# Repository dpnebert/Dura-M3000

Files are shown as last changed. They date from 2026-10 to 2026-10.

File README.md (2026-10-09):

# Dura M-3000

Firmware and hardware design files for the **Dura M-3000 liquid metering and pump-control system**.

The M-3000 uses an ESP32-S3 controller with a local LCD/keypad interface and Bluetooth Low Energy (BLE) communication for the Dura app. This project uses the single-meter M3000 configuration; the networked Dura V2 / ESP-NOW configuration is a separate product scope.

## Repository layout

```text
.
├── README.md
├── firmware/                 # ESP-IDF application, configuration and tests
│   ├── main/                 # Application startup and command handling
│   ├── components/           # Board support, metering, control and BLE modules
│   ├── scripts/              # Regression checks and development/bench utilities
│   ├── tests/                # Host-side test fixtures and supporting code
│   ├── tools/                # Asset conversion utilities
│   ├── CMakeLists.txt        # ESP-IDF project definition
│   ├── sdkconfig             # Saved project configuration
│   ├── sdkconfig.defaults    # Baseline configuration defaults
│   ├── dependencies.lock     # Resolved component and ESP-IDF versions
│   └── version.txt           # Build version identifier
└── hardware/                 # Schematic and PCB design files
```

## Functionality

- Flow measurement and volume display in gallons, liters and ounces.
- Manual dispensing, automatic batching and recirculation controls.
- Pump, injection-valve and recirculation-valve output control.
- Calibration workflows and persistent meter settings.
- Local LCD/keypad operation and BLE command handling.
- Battery monitoring, backlight control and deep-sleep support.

## Hardware platform

The firmware baseline targets the **PCB832 revX3 controller**, with the **PCB790 pump/relay interface** forming part of the system hardware.

| Item | Firmware baseline / intended system |
| --- | --- |
| Module | Espressif `ESP32-S3-WROOM-1-N8R2` |
| ESP-IDF target | `esp32s3` |
| Flash | 8 MB |
| PSRAM | Disabled in the firmware configuration |
| Display | 128 × 64 LCD with keypad input |
| Communications | BLE; UART0 for programming and console access |
| System power | Nominal 12 V lead-acid battery |
| CAD workflow | DipTrace |

Use the exact schematic, PCB revision and fitted parts for the unit being assembled. The nominal battery voltage is not a specification for the complete operating or transient voltage range. Hardware changes may require corresponding GPIO, polarity or configuration changes in the firmware.

## Build the firmware

### Prerequisites

- **ESP-IDF v6.0.2**, matching the checked-in dependency lockfile and verified project build baseline.
- The ESP32-S3 toolchain and Python environment installed through ESP-IDF.
- An activated ESP-IDF terminal. On Windows, use the ESP-IDF terminal or the ESP-IDF VS Code extension's terminal.

See Espressif's [ESP32-S3 setup guide](https://docs.espressif.com/projects/esp-idf/en/stable/esp32s3/get-started/) for environment installation. Use the project version above rather than assuming the latest SDK is interchangeable.

From the repository root:

```sh
cd firmware
idf.py --version
idf.py build
```

Build output is generated under `firmware/build/`, including the application image, bootloader, partition table and debug ELF. The application image is named `dura_m3000_firmware.bin`.

The saved configuration already selects `esp32s3`, 8 MB flash and disabled PSRAM. Preserve these settings unless intentionally changing the supported hardware.

To inspect or change project configuration from `firmware/`:

```sh
idf.py menuconfig
```

Board settings are under **Dura M3000 board**. Review configuration changes against the corresponding hardware revision before building a device image.

## Program and monitor a unit

**The normal configuration enables pump and valve outputs. Make connected loads safe before flashing, resetting or running commands.** Close other applications using the serial port before programming.

From `firmware/`, replace `PORT` with the connected programmer's serial port:

```sh
idf.py -p PORT flash monitor
```

The console is configured for UART0 at 115200 baud. Exit the monitor with `Ctrl+]`.

Use the board's programming interface and its schematic for wiring. Do not apply battery voltage to ESP32 GPIO or serial signals.

When programming prebuilt binaries instead of building locally, use the bootloader, partition table, application image and flash offsets from one matched release. The ELF is for debugging, not flashing. Do not perform a full-chip erase as a routine update; it removes persistent settings and calibration data.

## Tests and development tools

Host-side regression checks are in `firmware/scripts/`, with fixtures in `firmware/tests/`. They cover areas such as configuration/GPIO mapping, meter behavior, output ownership, BLE handling, UI contracts and battery processing.

For example, from `firmware/`, run the battery-history host regression with Python 3 and a compatible host C toolchain:

```sh
python scripts/test_battery_rolling_history.py
```

Some host checks use GNU compiler/linker features; a Linux development environment or WSL is appropriate for those checks. Read a script before running it: this directory also contains utilities that communicate with hardware, not only offline tests.

Passing a host regression or compiling successfully does not establish correct physical wiring, output polarity, electrical protection or complete app/device compatibility. Verify those on the matching hardware.

## Hardware design files

The [hardware directory](hardware/) contains the design files. Maintain schematic and PCB revisions together, and associate manufacturing outputs with the revision that generated them. Component substitutions must account for electrical ratings and the actual land pattern, not just package names.

The [firmware directory](firmware/) contains the application source and its build configuration. Keep firmware changes traceable to the hardware revision they support.

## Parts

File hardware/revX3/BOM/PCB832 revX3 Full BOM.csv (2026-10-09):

# | Quantity | Name | DIST P/N | Part No | Value | RefDes | Location
1 | 3 | CAP104-25V-0603 | CAP104-25V-0603 |  | 0.1uF | C1, C2, C9 | CT3/4-28 F
2 | 4 | CAP226-10V-0805 |  | GRM21BR61A226ME51L | 22uF | C3, C7, C8, C20 | NEW PART
3 | 1 | CAP106-16V-0805 | CAP106-16V-0805 |  | 10uF | C4 | CT3/3-13 B
4 | 7 | CAP105-25V-0603 | C0603C105Z3VACTU |  | 1uF | C5, C12, C13, C15, C16, C18, C19 | CT6/3-25B
5 | 1 | CAP100-50V-0603 | CAP100-50V-0603 |  | 10pF | C6 | CT3/4-25 B
6 | 2 | CAP105-16V-0603 | CAP105-16V-0603 |  | 1uF | C10, C11 | CT3/4-31 F
7 | 1 | CAP106-50V-1206 | CAP106-50V-1206 |  | 10uF | C14 | CT3/5-51 F
8 | 1 | CAP103-50V-0603 | C0603C103J5RAC7867 |  | 10nF | C17 | CT6/5-20 B
9 | 1 | GMC31X5R227M6R3NT |  |  | CAP227-6.3V-1206 | C21 | New Part
10 | 1 | MMSZ5231B-7-F | MMSZ5231B-7-F |  | 5.1V 500mW | D1
11 | 4 | BAT54S | BAT54S |  |  | D2, D3, D5, D7
12 | 1 | B02B-XASK-1-A(LF)(SN) |  |  |  | J1
13 | 1 | 3221-10-0300-00-TR |  |  | 3221-10-0300-00-TR | J4
14 | 1 | IND470nH_20pct |  |  | 0.47uH | L1 | NEW PART
15 | 1 | AIP0630GX-2R2MPBDG |  |  | 2.2uH | L2
16 | 4 | DMG3415U-7 | DMG3415U-7 |  | FET Pch | Q1, Q2, Q3, Q4 | CT3/5-13B
17 | 5 | 2N7002 | 2N7002 |  | FET Nch | Q5, Q6, Q7, Q8, Q9 | CT6/3-24 F
18 | 2 | 10.0KXT-0603 | 10.0KXT-0603 |  | 10.0K | R1, R32 | CT6/6-22 B
19 | 3 | 316KXE-0805 | CR0805-FX-3163ELF |  | 316K | R2, R9, R19 | NEW PART
20 | 13 | 100KT-0603 | 100KT-0603 |  | 100K | R3, R5, R6, R10, R11, R13, R15, R16, R20, R24, R25, R26, R29 | CT6/6-24 B
21 | 8 | 1.0KXT-0603 | 1.0KXT-0603 |  | 1.0K | R4, R12, R21, R22, R27, R28, R30, R31 | CT6/6-04 B
22 | 4 | 1.0MEX-0603 | RHM1.00MCTR-ND |  | 1M | R7, R8, R17, R18
23 | 1 | 22E-0805 | 22E-0805 |  | 22ohm | R14
24 | 1 | 95.3KXT-0603 |  |  | 95.3K | R23 | NEW PART
25 | 2 | MK15-B-2 |  |  |  | SW1, SW2
26 | 4 | DTSHW-677T-V | DTSHW-677T-V |  | SPST-NO | SW3, SW4, SW5, SW6 | UNKNOWN
27 | 1 | ESP32-S3-WROOM-1-N4R2 w/ longer pads |  |  | ESP32-S3-WROOM-1-N4R2 | U1
28 | 1 | PE12864WRF-042H36Q |  |  |  | U2
29 | 1 | TPS61021ADSGR |  |  |  | U3
30 | 1 | TPS62902RPJR |  |  | TPS62902RPJR | U4
31 | 1 | LM66100DCKR |  |  |  | U5
32 | 3 | SMAZ5V1-13-F | SMAZ5V1-13-F |  | 5.1V | Z1, Z2, Z3 | CT1/2-08

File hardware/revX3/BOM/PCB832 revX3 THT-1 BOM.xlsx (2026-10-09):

PCB832 revX3 THT-1 BOM
# | Quantity | Name | DIST P/N | RefDes | Location
1 | 1 | B02B-XASK-1-A(LF)(SN) |  | J1 | UNKNOWN
2 | 4 | DTSHW-677T-V | DTSHW-677T-V | SW3, SW4, SW5, SW6 | UNKNOWN
3 | 1 | PE12864WRF-042H36Q | PE12864WRF-042H36Q | J1 | UNKNOWN

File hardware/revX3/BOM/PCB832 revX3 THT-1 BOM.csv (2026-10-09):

# | Quantity | Name | DIST P/N | Part No | Value | RefDes | Location
1 | 1 | B02B-XASK-1-A(LF)(SN) |  |  |  | J1
2 | 4 | DTSHW-677T-V | DTSHW-677T-V |  | SPST-NO | SW3, SW4, SW5, SW6 | UNKNOWN

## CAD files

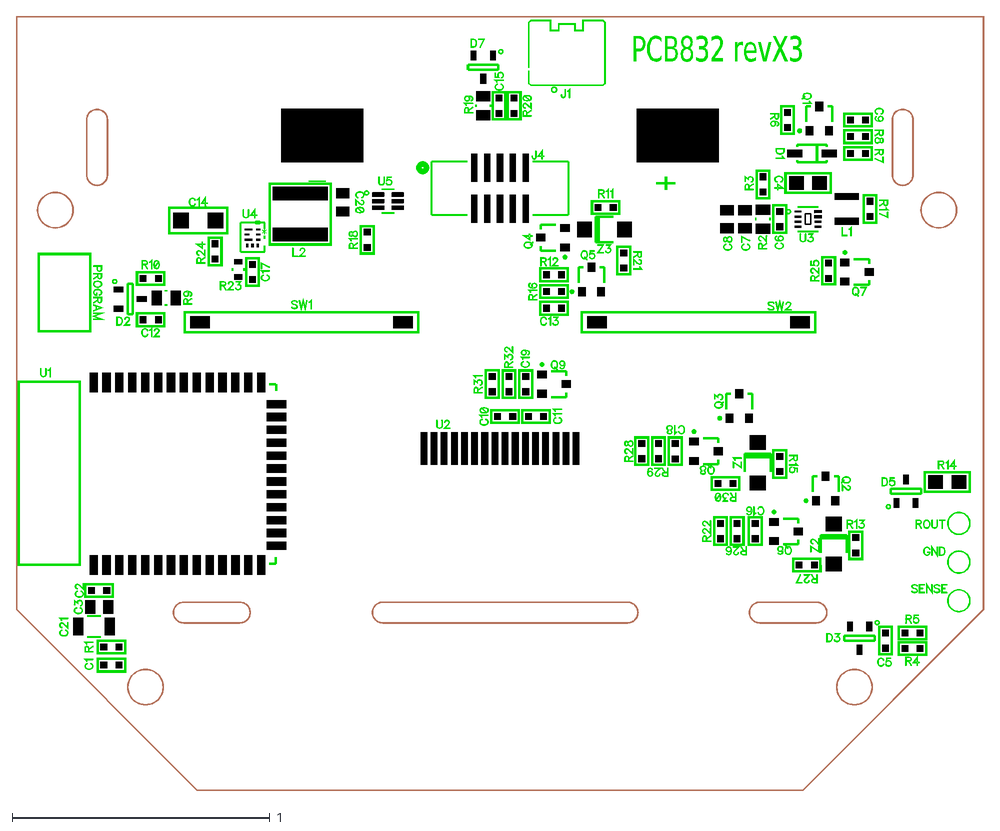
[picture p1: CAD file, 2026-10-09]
hardware/revX3/DRAWING/PCB832 revX3 SMT Ref.dxf
*
+
|
PCB832 revX3

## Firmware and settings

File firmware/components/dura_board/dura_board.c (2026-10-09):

#include "dura_board.h"
#include "gama_blefob.h"
#include "dura_battery.h"
#include "dura_st7567.h"
#include "dura_meter.h"
#include "dura_coordinator.h"
#include "dura_peers.h"
#include "dura_recipe.h"
#include "dura_lcd_assets.h"
#include "dura_ui_behavior.h"
#include "dura_ui_config.h"

#include <math.h>
#include <stdbool.h>
#include <stdio.h>
#include <string.h>
#include <strings.h>
#include "button_gpio.h"
#include "iot_button.h"
#include "driver/gpio.h"
#include "driver/rtc_io.h"
#include "esp_attr.h"
#include "esp_check.h"
#include "esp_log.h"
#include "esp_sleep.h"
#include "esp_timer.h"
#include "freertos/FreeRTOS.h"
#include "freertos/queue.h"
#include "freertos/task.h"
#include "qrcode.h"

static const char *TAG = "dura_board";
#define DURA_BOOT_LOGO_HOLD_MS 500u
#define DURA_BOOT_POWERING_UP_HOLD_MS 2000u
#define DURA_AUTO_BATCH_DEFAULT_GAL 10.0f
#define DURA_RECIRC_BATCH_DEFAULT_GAL 250.0f

static volatile uint32_t s_flow_pulses;
static portMUX_TYPE s_flow_mux = portMUX_INITIALIZER_UNLOCKED;
/* DRAM spinlock shared with the IRAM ISR; never acquire the meter from ISR. */
static portMUX_TYPE s_flow_boundary_mux = portMUX_INITIALIZER_UNLOCKED;
static QueueHandle_t s_flow_event_queue;
static portMUX_TYPE s_ui_snapshot_mux = portMUX_INITIALIZER_UNLOCKED;
static TaskHandle_t s_task;
static QueueHandle_t s_button_queue;
static dura_board_ui_snapshot_t s_ui_snapshot;
static bool s_ui_snapshot_valid;
static dura_board_ui_change_cb_t s_ui_change_cb;
static void *s_ui_change_context;
static bool s_ble_connected;
static int64_t s_last_activity_us;
/* Illumination is independent of sleep admission/connection bookkeeping. */
static int64_t s_backlight_activity_us;
static uint64_t s_activity_generation;
/* Only board_task touches preparation/recovery state and input muxes. */
static bool s_sleep_requested;
static bool s_sleep_recovery_pending;
static uint64_t s_sleep_touched_mask;
static bool s_sleep_ext1_attempted;
static bool s_ignore_buttons_until_release;
static void publish_ui_snapshot(const dura_meter_snapshot_t *meter);

esp_err_t dura_board_get_ui_snapshot(dura_board_ui_snapshot_t *snapshot)
{
    if (snapshot == NULL) return ESP_ERR_INVALID_ARG;
    portENTER_CRITICAL(&s_ui_snapshot_mux);
    if (!s_ui_snapshot_valid) {
        portEXIT_CRITICAL(&s_ui_snapshot_mux);
        return ESP_ERR_INVALID_STATE;
    }
    *snapshot = s_ui_snapshot;
    portEXIT_CRITICAL(&s_ui_snapshot_mux);
    return ESP_OK;
}

esp_err_t dura_board_set_ui_change_callback(dura_board_ui_change_cb_t callback, void *context)
{
    portENTER_CRITICAL(&s_ui_snapshot_mux);
    s_ui_change_cb = callback;
    s_ui_change_context = context;
    portEXIT_CRITICAL(&s_ui_snapshot_mux);
    return ESP_OK;
}

esp_err_t dura_board_set_ble_connected(bool connected)
{
    portENTER_CRITICAL(&s_ui_snapshot_mux);
    s_ble_connected = connected;
    ++s_activity_generation;
    s_last_activity_us = esp_timer_get_time();
    portEXIT_CRITICAL(&s_ui_snapshot_mux);
    return ESP_OK;
}

void dura_board_note_activity(void)
{
    const int64_t now_us = esp_timer_get_time();
    portENTER_CRITICAL(&s_ui_snapshot_mux);
    s_last_activity_us = now_us;
    ++s_activity_generation;
    portEXIT_CRITICAL(&s_ui_snapshot_mux);
}
void dura_board_note_user_activity(void)
{
    const int64_t now_us = esp_timer_get_time();
    portENTER_CRITICAL(&s_ui_snapshot_mux);
    s_last_activity_us = now_us;
    s_backlight_activity_us = now_us;
    ++s_activity_generation;
    portEXIT_CRITICAL(&s_ui_snapshot_mux);
}

/* Board owner only: callers on other tasks record activity, never drive GPIO.
 * No calibration exception. OFF (9) wins over every activity source. */
static void update_backlight(void)
{
    dura_meter_snapshot_t meter;
    if (dura_meter_get_snapshot(&meter) != ESP_OK) {
        (void)dura_lcd_set_backlight(false);
        return;
    }
    portENTER_CRITICAL(&s_ui_snapshot_mux);
    const int64_t activity_us = s_backlight_activity_us;
    portEXIT_CRITICAL(&s_ui_snapshot_mux);
    const int64_t now_us = esp_timer_get_time();
    const int64_t elapsed_us = now_us >= activity_us ? now_us - activity_us : 0;
    const bool on = meter.backlight_timeout_sec >= DURA_BACKLIGHT_TIMEOUT_MIN_SEC &&
                    meter.backlight_timeout_sec <= DURA_BACKLIGHT_TIMEOUT_MAX_SEC &&
                    elapsed_us < (int64_t)meter.backlight_timeout_sec * 1000000LL;
    (void)dura_lcd_set_backlight(on);
}

RTC_DATA_ATTR static bool s_provisioning_qr_dismissed;
static bool s_provisioning_qr_rendered;
static bool s_boost_enabled;
static char s_provisioning_qr_payload[80];

typedef struct {
    dura_button_t id;
    gpio_num_t gpio;
    const char *name;
    button_handle_t handle;
} dura_button_def_t;
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

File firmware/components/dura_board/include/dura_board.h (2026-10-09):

#pragma once

#include <stdbool.h>
#include <stdint.h>
#include "driver/gpio.h"
#include "esp_err.h"
#include "hal/adc_types.h"
#include "sdkconfig.h"

#ifdef __cplusplus
extern "C" {
#endif

// Dura M3000 board wiring is selected through CONFIG_DURA_BOARD_* Kconfig options.
// GPIO numbers, input biasing, and active levels are editable in menuconfig.
// Default hardware is PCB832 revX3 with ESP32-S3-WROOM-1-N8R2 (8 MB flash).
// Avoid GPIO22-GPIO25 because they are invalid on ESP32-S3.
// Reserve module flash/PSRAM memory-bus pins; PSRAM is present but unused by policy.
#ifndef CONFIG_DURA_BOARD_S3_WROOM_1
#define CONFIG_DURA_BOARD_S3_WROOM_1 1
#define CONFIG_DURA_BOARD_NAME "ESP32-S3-WROOM-1"
#endif
#ifndef CONFIG_DURA_BOARD_ENABLE_HARDWARE_TASK
#define CONFIG_DURA_BOARD_ENABLE_HARDWARE_TASK 0
#endif
#ifndef CONFIG_DURA_BOARD_ENABLE_PUMP_OUTPUT
#define CONFIG_DURA_BOARD_ENABLE_PUMP_OUTPUT 0
#endif
#ifndef CONFIG_DURA_BOARD_ENABLE_EV_OUTPUTS
#define CONFIG_DURA_BOARD_ENABLE_EV_OUTPUTS 0
#endif
#ifndef CONFIG_DURA_BOARD_ENABLE_RECIRC_INPUT
#define CONFIG_DURA_BOARD_ENABLE_RECIRC_INPUT 0
#endif
#ifndef CONFIG_DURA_BOARD_ENABLE_DEEP_SLEEP
#define CONFIG_DURA_BOARD_ENABLE_DEEP_SLEEP 0
#endif
#ifndef CONFIG_DURA_BOARD_ENABLE_LEGACY_POWER_OUTPUTS
#define CONFIG_DURA_BOARD_ENABLE_LEGACY_POWER_OUTPUTS 0
#endif
#ifndef CONFIG_DURA_BOARD_ENABLE_EXT_POWER_PRESENT_INPUT
#define CONFIG_DURA_BOARD_ENABLE_EXT_POWER_PRESENT_INPUT 0
#endif
#ifndef CONFIG_DURA_BOARD_BLE_REQUIRES_EXT_POWER
#define CONFIG_DURA_BOARD_BLE_REQUIRES_EXT_POWER 0
#endif
#ifndef CONFIG_DURA_BOARD_GPIO_EXT_POWER_PRESENT
#define CONFIG_DURA_BOARD_GPIO_EXT_POWER_PRESENT 3
#endif

#ifndef CONFIG_DURA_BOARD_FLOW_ACTIVE_LOW
#define CONFIG_DURA_BOARD_FLOW_ACTIVE_LOW 0
#endif
#ifndef CONFIG_DURA_BOARD_FLOW_PULLUP
#define CONFIG_DURA_BOARD_FLOW_PULLUP 0
#endif
#ifndef CONFIG_DURA_BOARD_FLOW_PULLDOWN
#define CONFIG_DURA_BOARD_FLOW_PULLDOWN 0
#endif
#ifndef CONFIG_DURA_BOARD_BUTTON_ACTIVE_LOW
#define CONFIG_DURA_BOARD_BUTTON_ACTIVE_LOW 0
#endif
#ifndef CONFIG_DURA_BOARD_BUTTON_PULLUP
#define CONFIG_DURA_BOARD_BUTTON_PULLUP 0
#endif
#ifndef CONFIG_DURA_BOARD_BUTTON_PULLDOWN
#define CONFIG_DURA_BOARD_BUTTON_PULLDOWN 0
#endif
#ifndef CONFIG_DURA_BOARD_LCD_CS_ACTIVE_LOW
#define CONFIG_DURA_BOARD_LCD_CS_ACTIVE_LOW 0
#endif
#ifndef CONFIG_DURA_BOARD_LCD_RST_ACTIVE_LOW
#define CONFIG_DURA_BOARD_LCD_RST_ACTIVE_LOW 0
#endif
#ifndef CONFIG_DURA_BOARD_LCD_BACKLIGHT_ACTIVE_LOW
#define CONFIG_DURA_BOARD_LCD_BACKLIGHT_ACTIVE_LOW 0
#endif
#ifndef CONFIG_DURA_BOARD_PUMP_OUTPUT_ACTIVE_LOW
#define CONFIG_DURA_BOARD_PUMP_OUTPUT_ACTIVE_LOW 0
#endif
#ifndef CONFIG_DURA_BOARD_RECIRC_INPUT_ACTIVE_LOW
#define CONFIG_DURA_BOARD_RECIRC_INPUT_ACTIVE_LOW 0
#endif
#ifndef CONFIG_DURA_BOARD_RECIRC_INPUT_PULLUP
#define CONFIG_DURA_BOARD_RECIRC_INPUT_PULLUP 0
#endif
#ifndef CONFIG_DURA_BOARD_RECIRC_INPUT_PULLDOWN
#define CONFIG_DURA_BOARD_RECIRC_INPUT_PULLDOWN 0
#endif
#ifndef CONFIG_DURA_BOARD_RECIRC_EV_OUTPUT_ACTIVE_LOW
#define CONFIG_DURA_BOARD_RECIRC_EV_OUTPUT_ACTIVE_LOW 0
#endif
#ifndef CONFIG_DURA_BOARD_INJECT_EV_OUTPUT_ACTIVE_LOW
#define CONFIG_DURA_BOARD_INJECT_EV_OUTPUT_ACTIVE_LOW 0
#endif
#ifndef CONFIG_DURA_BOARD_BOOST_ENABLE_ACTIVE_LOW
#define CONFIG_DURA_BOARD_BOOST_ENABLE_ACTIVE_LOW 0
#endif
#ifndef CONFIG_DURA_BOARD_BOOST_DISABLE_ACTIVE_LOW
#define CONFIG_DURA_BOARD_BOOST_DISABLE_ACTIVE_LOW 0
#endif
#ifndef CONFIG_DURA_BOARD_BATTERY_DISCONNECT_ACTIVE_LOW
#define CONFIG_DURA_BOARD_BATTERY_DISCONNECT_ACTIVE_LOW 0
#endif
#ifndef CONFIG_DURA_BOARD_SW_LO_ENABLE1_ACTIVE_LOW
#define CONFIG_DURA_BOARD_SW_LO_ENABLE1_ACTIVE_LOW 0
#endif
#ifndef CONFIG_DURA_BOARD_SW_LO_ENABLE2_ACTIVE_LOW
#define CONFIG_DURA_BOARD_SW_LO_ENABLE2_ACTIVE_LOW 0
#endif
#ifndef CONFIG_DURA_BOARD_EXT_POWER_PRESENT_ACTIVE_LOW
#define CONFIG_DURA_BOARD_EXT_POWER_PRESENT_ACTIVE_LOW 0
#endif
#ifndef CONFIG_DURA_BOARD_EXT_POWER_PRESENT_PULLUP
#define CONFIG_DURA_BOARD_EXT_POWER_PRESENT_PULLUP 0
#endif
#ifndef CONFIG_DURA_BOARD_EXT_POWER_PRESENT_PULLDOWN
#define CONFIG_DURA_BOARD_EXT_POWER_PRESENT_PULLDOWN 0
#endif
#define DURA_GPIO_FROM_CONFIG(name)        ((gpio_num_t)CONFIG_DURA_BOARD_GPIO_##name)
#define DURA_ACTIVE_LEVEL(active_low)      ((active_low) ? 0 : 1)
#define DURA_INACTIVE_LEVEL(active_low)    ((active_low) ? 1 : 0)
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
